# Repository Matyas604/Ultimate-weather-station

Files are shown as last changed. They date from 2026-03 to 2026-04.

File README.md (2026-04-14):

# Ultimate weather station
For a long time, I’ve wanted to know the current temperature, humidity, air quality, and more outside. Since weather forecasts are never accurate for my exact location, I wanted to know what the conditions really are. So, since I already have a lot of experience, I decided to build a complete weather station that would measure the values I wanted, based exactly on the sensors I chose. And since I have a [Home Assistant](https://www.home-assistant.io/) at home, I could make the station smart and monitor the data from anywhere.

This project was more about 3D modeling than PCB design, but in the end, I’m very satisfied.

## Features
- **Contains sensors:** [SHT45](https://sensirion.com/media/documents/33FD6951/67EB9032/HT_DS_Datasheet_SHT4x_5.pdf), [BMP280](https://www.bosch-sensortec.com/media/boschsensortec/downloads/datasheets/bst-bmp280-ds001.pdf), [SGP41](https://sensirion.com/media/documents/5FE8673C/61E96F50/Sensirion_Gas_Sensors_Datasheet_SGP41.pdf), and the [AS3935](https://cdn.sparkfun.com/assets/learn_tutorials/9/2/1/AS3935_Datasheet_EN_v2.pdf) and [LM393](https://www.onsemi.com/download/data-sheet/pdf/lm393-d.pdf) integrated circuits  
- **It can measure:** [temperature](https://en.wikipedia.org/wiki/Temperature), [humidity](https://en.wikipedia.org/wiki/Humidity), [pressure](https://en.wikipedia.org/wiki/Atmospheric_pressure), [air quality](https://en.wikipedia.org/wiki/Air_quality_index), [lightning distance and energy](https://en.wikipedia.org/wiki/Lightning), [wind speed](https://en.wikipedia.org/wiki/Wind_speed) and whether it is raining
- It's connected to [Home Assistant](https://www.home-assistant.io/), so I can use the data to set up automations and monitor the readings even when I'm not at home
- The [ESP32-S3](https://documentation.espressif.com/esp32-s3_datasheet_en.pdf) is the brain of the entire station
- It has two PCBs, one main board and another with sensors located inside the [radiation shield](https://en.wikipedia.org/wiki/Stevenson_screen) that measure the readings. They are connected to each other with a 7-wire cable
- It has pull-up resistors for I2C on the main board, additional resistors can be added on the sensor board to extend the cable length beyond 2 meters
- It is programmable via USB-C
- It is powered by a 5V two-wire cable

⚠️The screw and nuts for the anemometer and the rods for the radiation shield must be made of brass, because brass is non-magnetic and therefore will not interfere with the lightning detection antenna, unlike iron or steel!

## CAD model
It includes a box for the main board and a radiation shield, which is secured with M5 rods and nuts, on top is an anemometer propeller for measuring wind speed. I’ll be placing the weather station on the balcony, so I’ve made a mount for it. It will be attached to the railing, which has a 14° slope, so the mount is designed to keep the radiation shield straight. The shield is connected to the mount with an M6 rod and M6 nuts, there is also a mount for the rain sensor. The railing mount is secured with two parts connected by M6 bolts and nuts. **All parts must be printed using at least ABS, but ASA would be much better, they must also be white!** They will be kept outdoors permanently, and ASA is a material that is highly resistant to UV radiation, sunlight, and rain. It is also very strong, so it can withstand strong winds.

<p align="center">
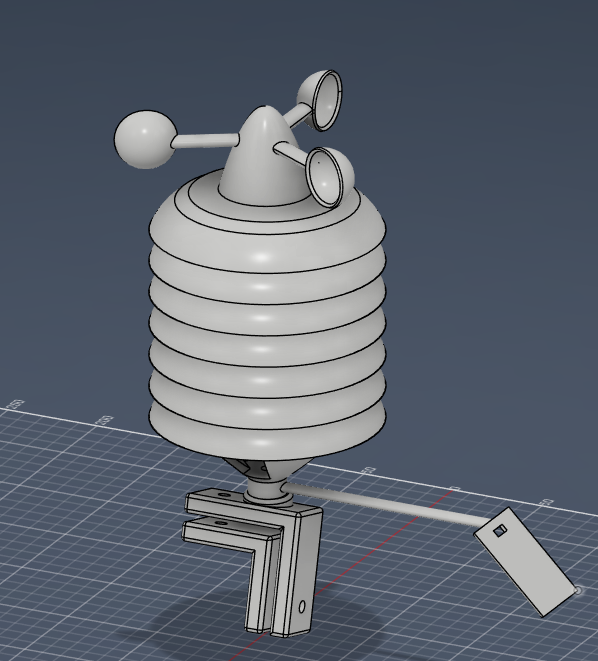
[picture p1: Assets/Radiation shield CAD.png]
Radiation shield CAD
  
</p>
<p align="center">
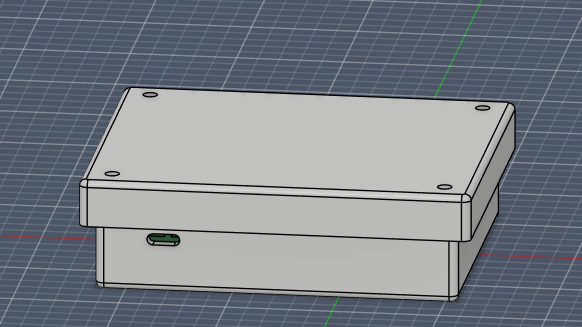
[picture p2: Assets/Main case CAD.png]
Main case CAD
  
</p>
<p align="center">
  <strong>Made in Fusion360</strong>
</p>

## PCBs
### Main PCB:
<p align="center">
  Schematic
</p>
<p align="center">
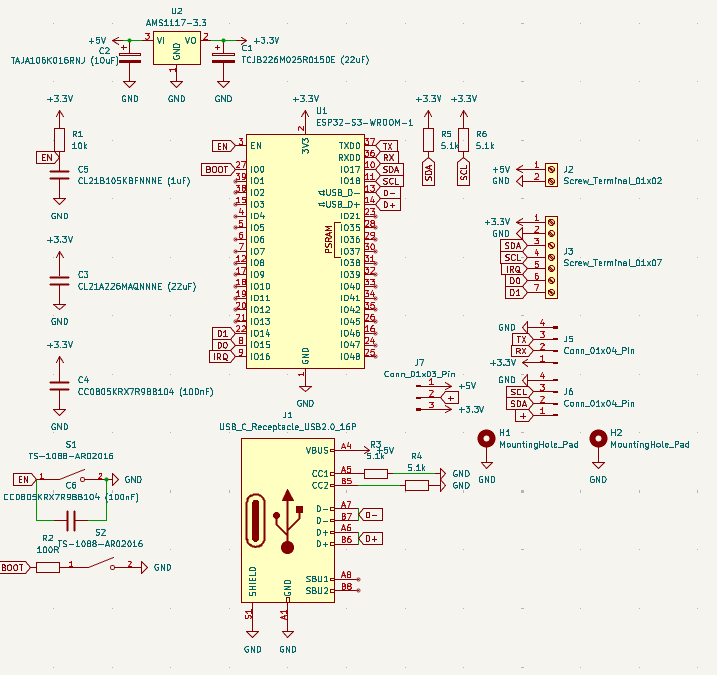
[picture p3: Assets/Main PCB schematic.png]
Main PCB schematic
  
</p>
<p align="center">
  PCB
</p>
<p align="center">
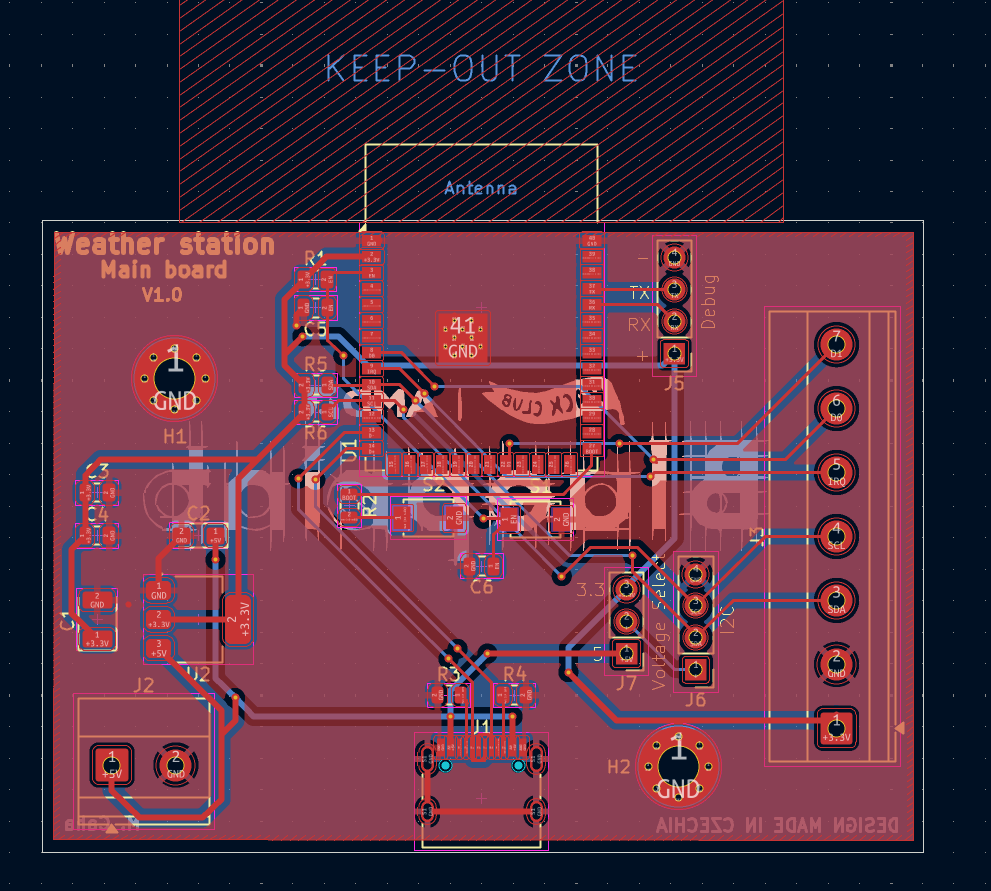
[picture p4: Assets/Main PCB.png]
Main PCB
  
</p>

### Sensors PCB:
<p align="center">
  Schematic
</p>
<p align="center">
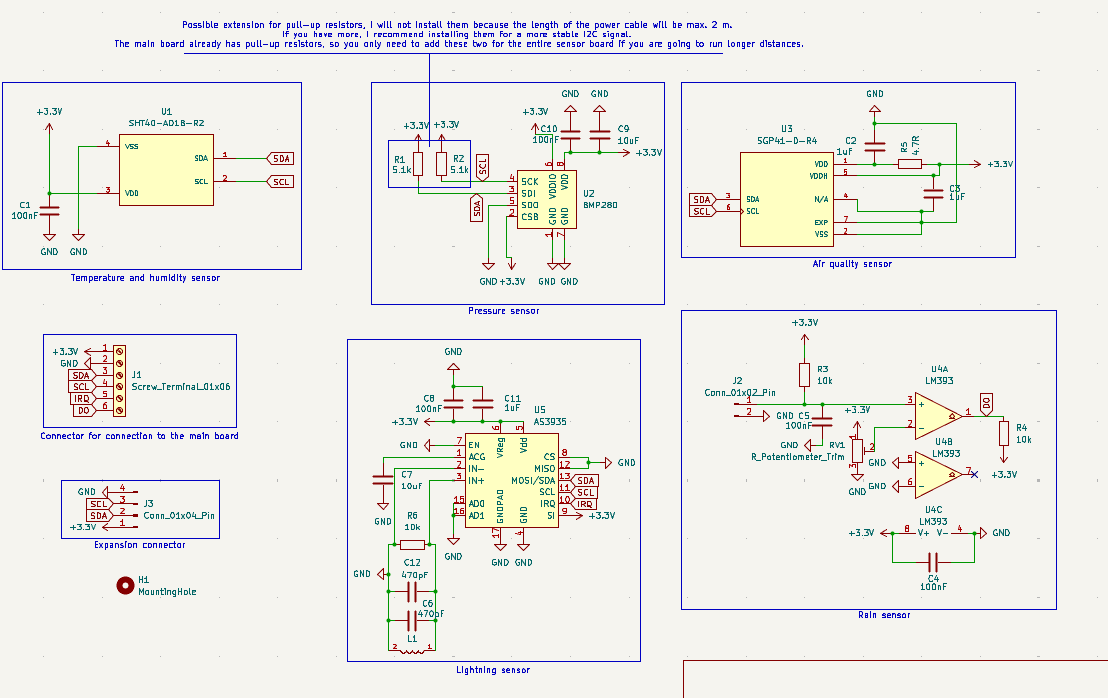
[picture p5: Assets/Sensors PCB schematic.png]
Sensors PCB schematic
  
</p>
<p align="center">
  PCB
</p>
<p align="center">
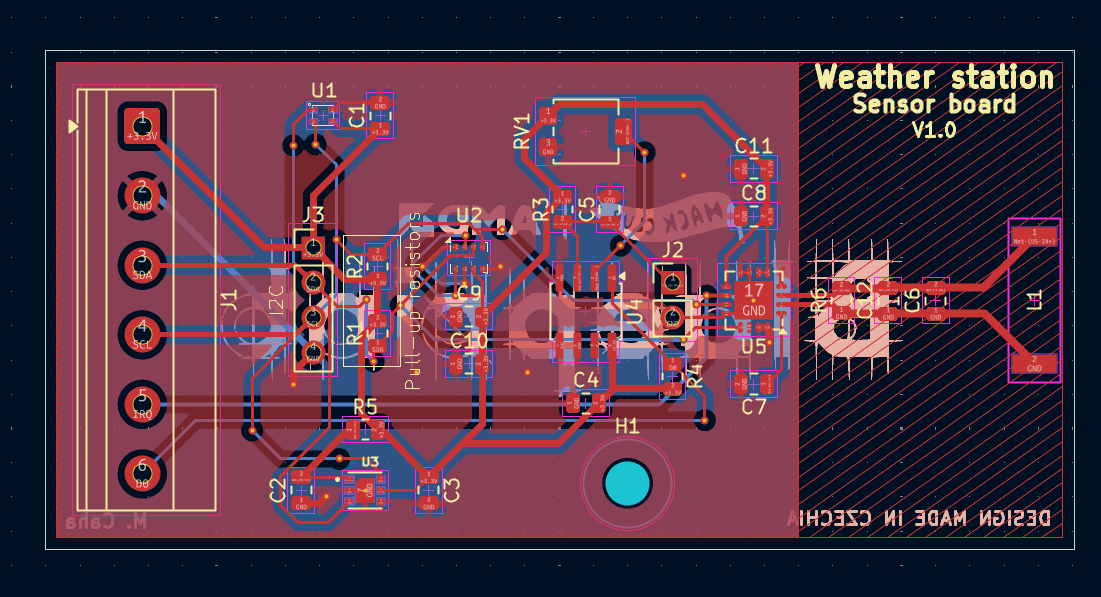
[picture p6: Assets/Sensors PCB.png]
Sensors PCB
  
</p>
<p align="center">
  <strong>Made in KiCad</strong>
</p>

## Wiring diagram
<p align="center">
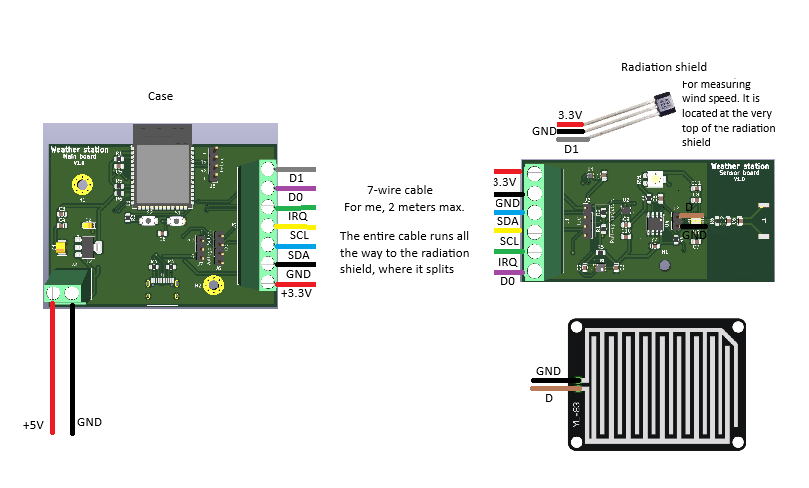
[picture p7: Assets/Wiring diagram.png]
Wiring diagram
  
</p>

## Firmware
This weather station uses [ESPHome](https://esphome.io/) firmware. It is programmed via the USB-C port on the main board. Thanks to ESPHome, it connects to [Home Assistant](https://www.home-assistant.io/), where I can then create various automations and view data from anywhere.

## BOM
It's very long, so you can find it in .csv format [here](https://github.com/Matyas604/Ultimate-weather-station/blob/main/BOM.csv).  
Please read additional information about the BOM [here](https://github.com/Matyas604/Ultimate-weather-station/blob/main/BOM%20info.md).

## Notes for v2 upgrades
Since I anticipated potential upgrades, I added additional I2C ports to both the main board and the sensor board. On the main board, you can also select a voltage of 5V or 3.3V, so you can connect a lot of other things. I did this so I wouldn’t have to replace the entire board when adding expansions. The main board also features a very powerful ESP32, which has enough performance for further expansion. I plan to add the following over time:
- A rain gauge that measures the amount of rainfall
- A dust sensor for measuring **PM1.0**, **PM2.5**, **PM4**, and **PM10** particles, which can then be used in combination with the **SGP41** to calculate air [**Quality Index (AQI)**](https://en.wikipedia.org/wiki/Air_quality_index) values
- Wind direction
- UV and light sensor

## License
This project is licensed under the GNU GPL v3.
```
Matyas604/Ultimate-weather-station - Custom weather station for Home Assistant running on an ESP32
Copyright (C) 2026 Matyáš Caha

This program is free software: you can redistribute it and/or modify
it under the terms of the GNU General Public License as published by
the Free Software Foundation, either version 3 of the License, or
(at your option) any later version.

This program is distributed in the hope that it will be useful,
but WITHOUT ANY WARRANTY; without even the implied warranty of
MERCHANTABILITY or FITNESS FOR A PARTICULAR PURPOSE. See the
GNU General Public License for more details.

You should have received a copy of the GNU General Public License
along with this program. If not, see <https://www.gnu.org/licenses/>.
```

<hr>

<p align="center">
  Made with ❤️ by <a href="https://github.com/Matyas604">@Matyas604</a>
</p>

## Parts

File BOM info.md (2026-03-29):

|Total|Price (USD)|Description|
|-|:-:|:-:|
|**BOM Total**|184.54|Total amount|
|**BOM Total without screws and nuts**|168.77|Total amount without steel screws and nuts|

## Some information about the BOM:

The **AS3935** and **MA5532-AE** components aren’t available on LCSC, but only on other websites where shipping costs $30. So I’ll buy the module from AliExpress, desolder these two components from it, and then use them on my PCB. This will be the best approach, because 95% of the module’s price is for the components, and shipping is free. The **MA5532-AE** component will desolder very easily, and since the **AS3935** has no pins, it will also desolder very easily and without damage.  
**Websites where these components are available:**  
[AS3935](https://cz.mouser.com/ProductDetail/ScioSense/AS3935-BQFT?qs=YVUHYZFLFLudUiUyjH%252FhsQ%253D%253D)  
[MA5532-AE](https://www.coilcraft.com/en-us/products/rf/rfid-transponders/x-y-axis-transponder-coil-2mhz/ma5532/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)

Above, I listed the total amount and the amount excluding steel screws and nuts. If the total amount is too high, I can buy the screws at a local hardware store, where I can purchase exactly the number of pieces I need for cheap. On AliExpress, there aren’t any listings that contain just a few screws or nuts; they come in packs of dozens, which is why they’re so expensive. I need some specific screws and nuts (the brass ones) which I can’t just buy at a regular store, and they’re there specifically so they don’t interfere with the lightning sensor.  

I originally wanted to have the PCB manufactured through JLCPCBA because they would have all the components on hand, but the **SHT45**, **SGP41**, and **BMP280** sensors are very sensitive to high-temperature soldering. JLCPCBA charges an extra $30 for low-temperature soldering, not including the assembly cost, so I’ll save a lot even if I have to pay more for shipping. I have low-temperature solder paste and a hot plate, so I won’t damage the sensors. I already have plenty of experience with SMD soldering.

## Cart photos:
### JLCPCB:
<p align="center">
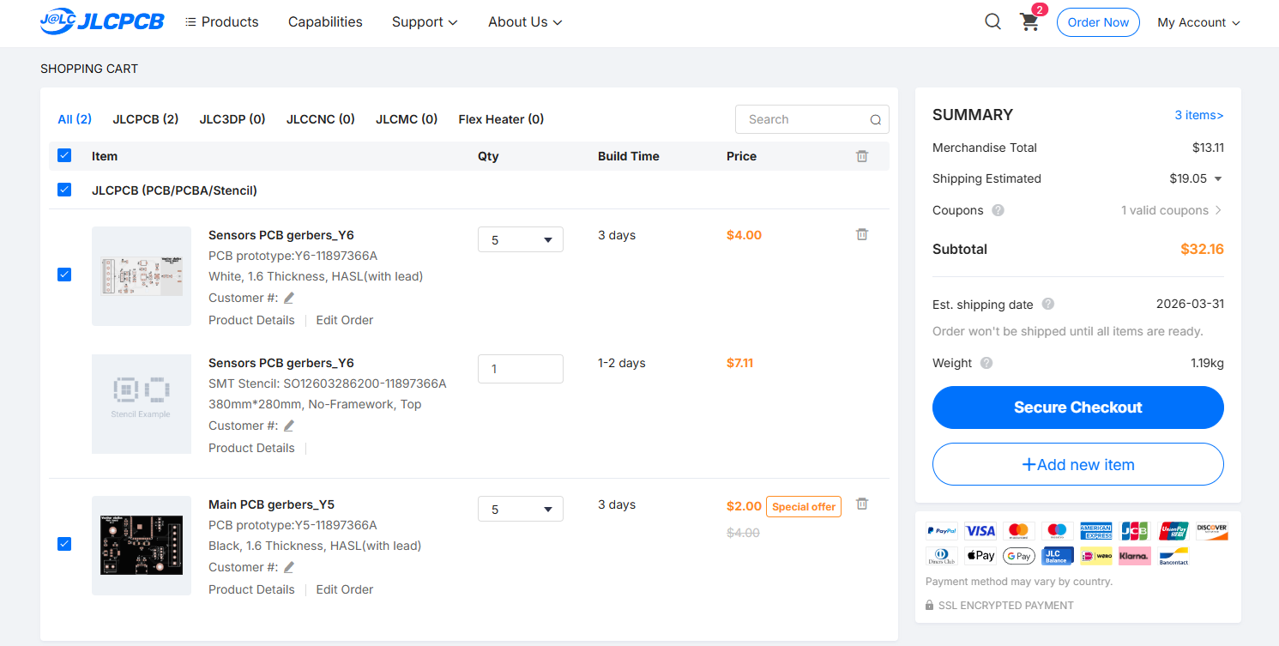
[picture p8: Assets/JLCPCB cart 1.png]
JLCPCB cart 1
  
</p>
<p align="center">
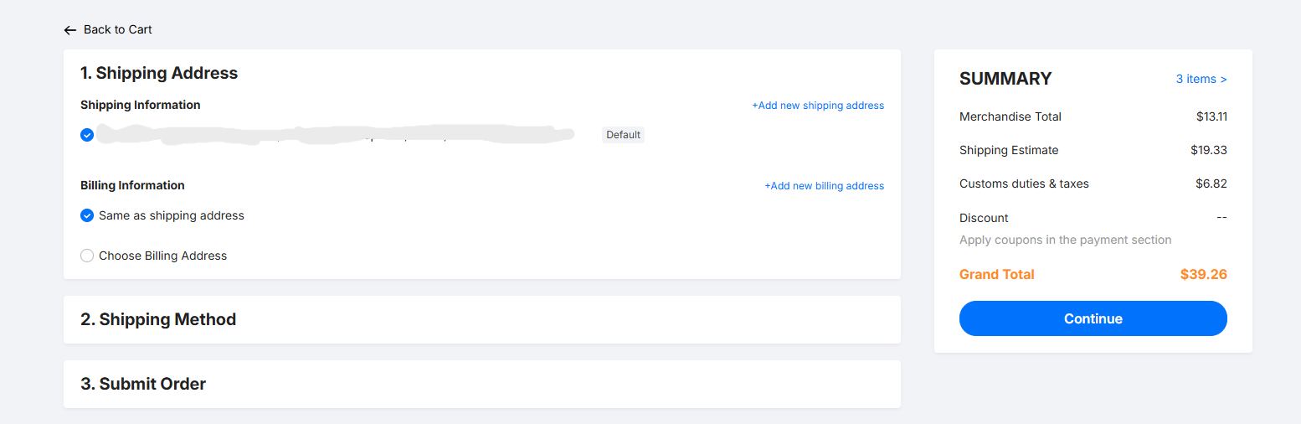
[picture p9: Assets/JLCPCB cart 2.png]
JLCPCB cart 2
  
</p>

### LCSC:
<p align="center">
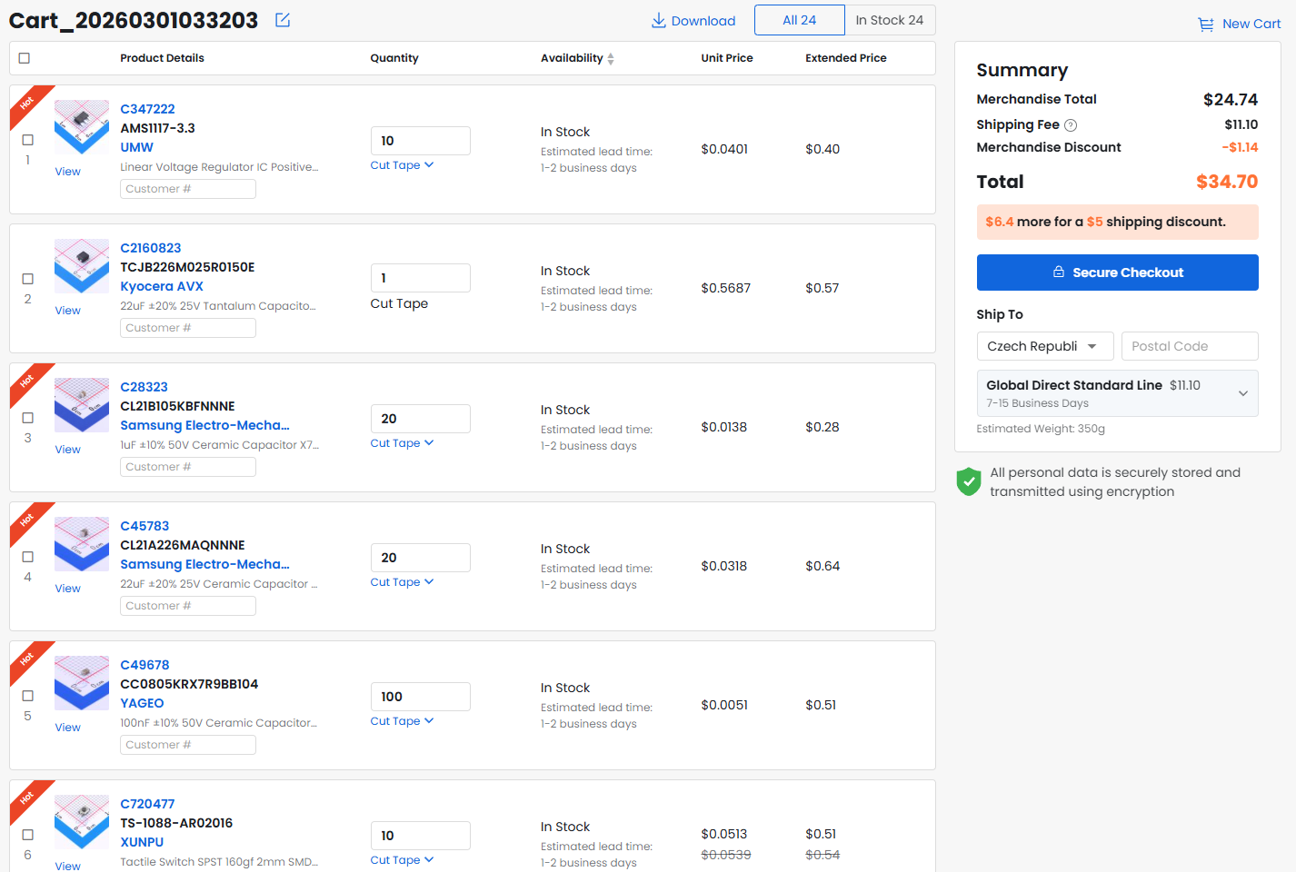
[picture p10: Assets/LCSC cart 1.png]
LCSC cart 1
  
</p>
<p align="center">
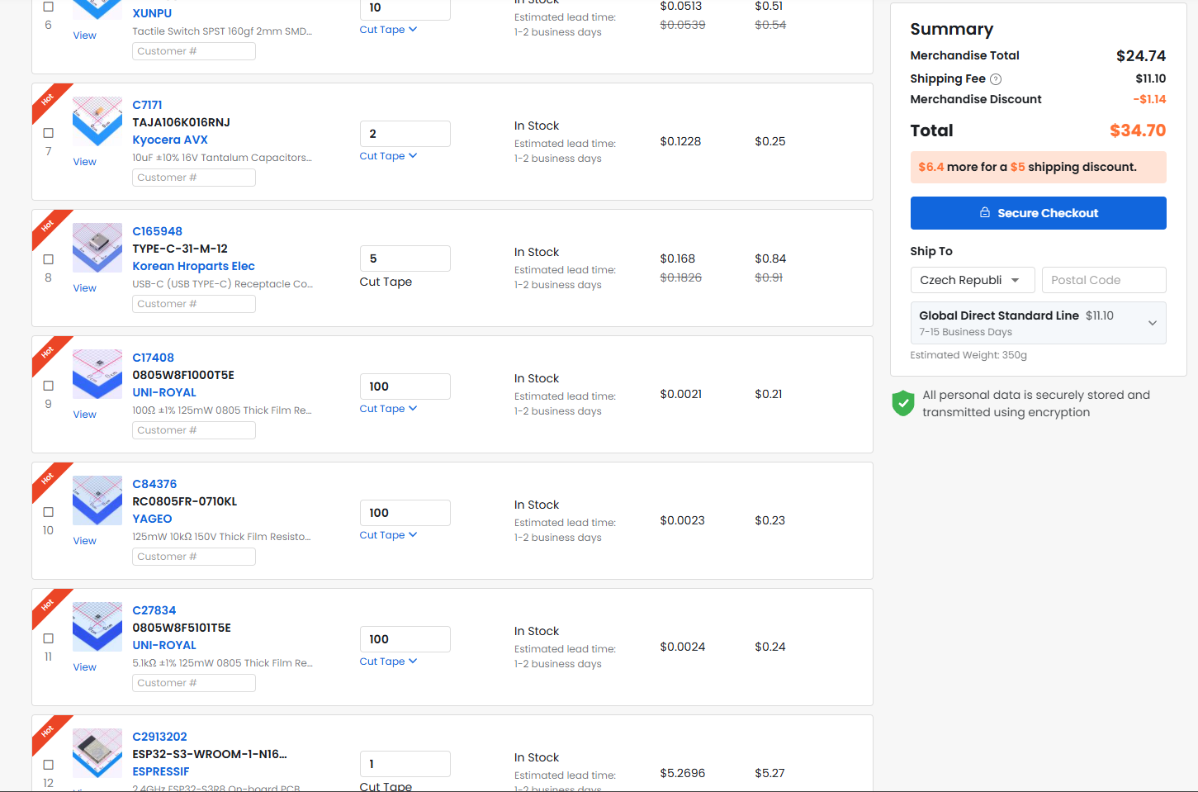
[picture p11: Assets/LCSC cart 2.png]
LCSC cart 2
  
</p>
<p align="center">
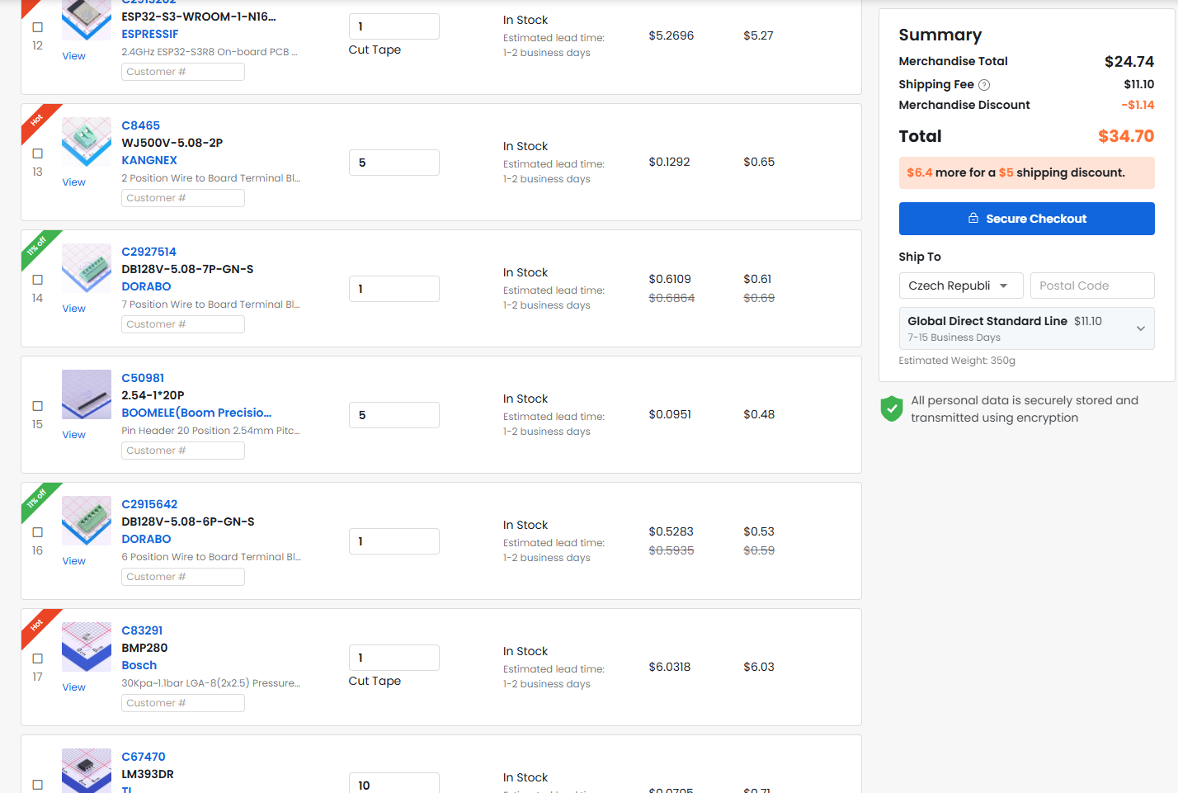
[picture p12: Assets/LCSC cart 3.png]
LCSC cart 3
  
</p>
<p align="center">
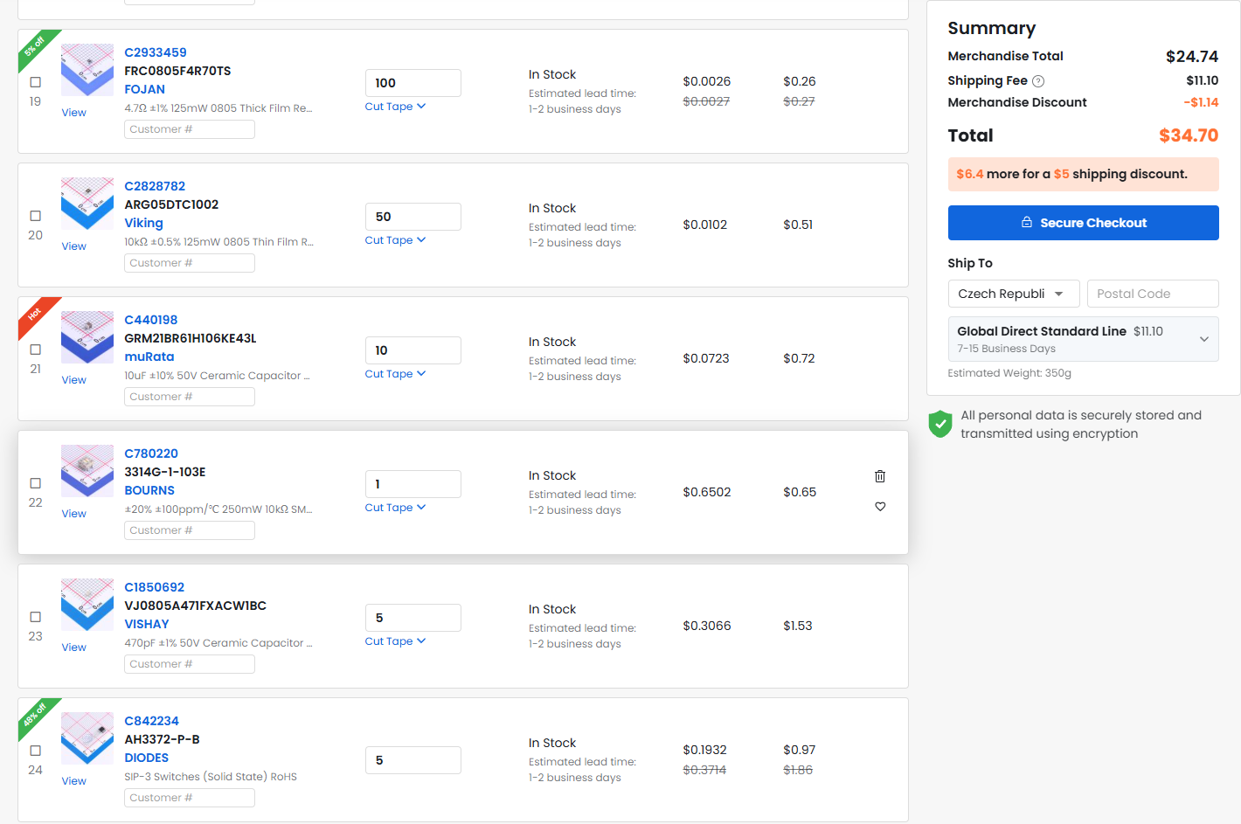
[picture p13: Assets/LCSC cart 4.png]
LCSC cart 4
  
</p>

### Aliexpress:
<p align="center">
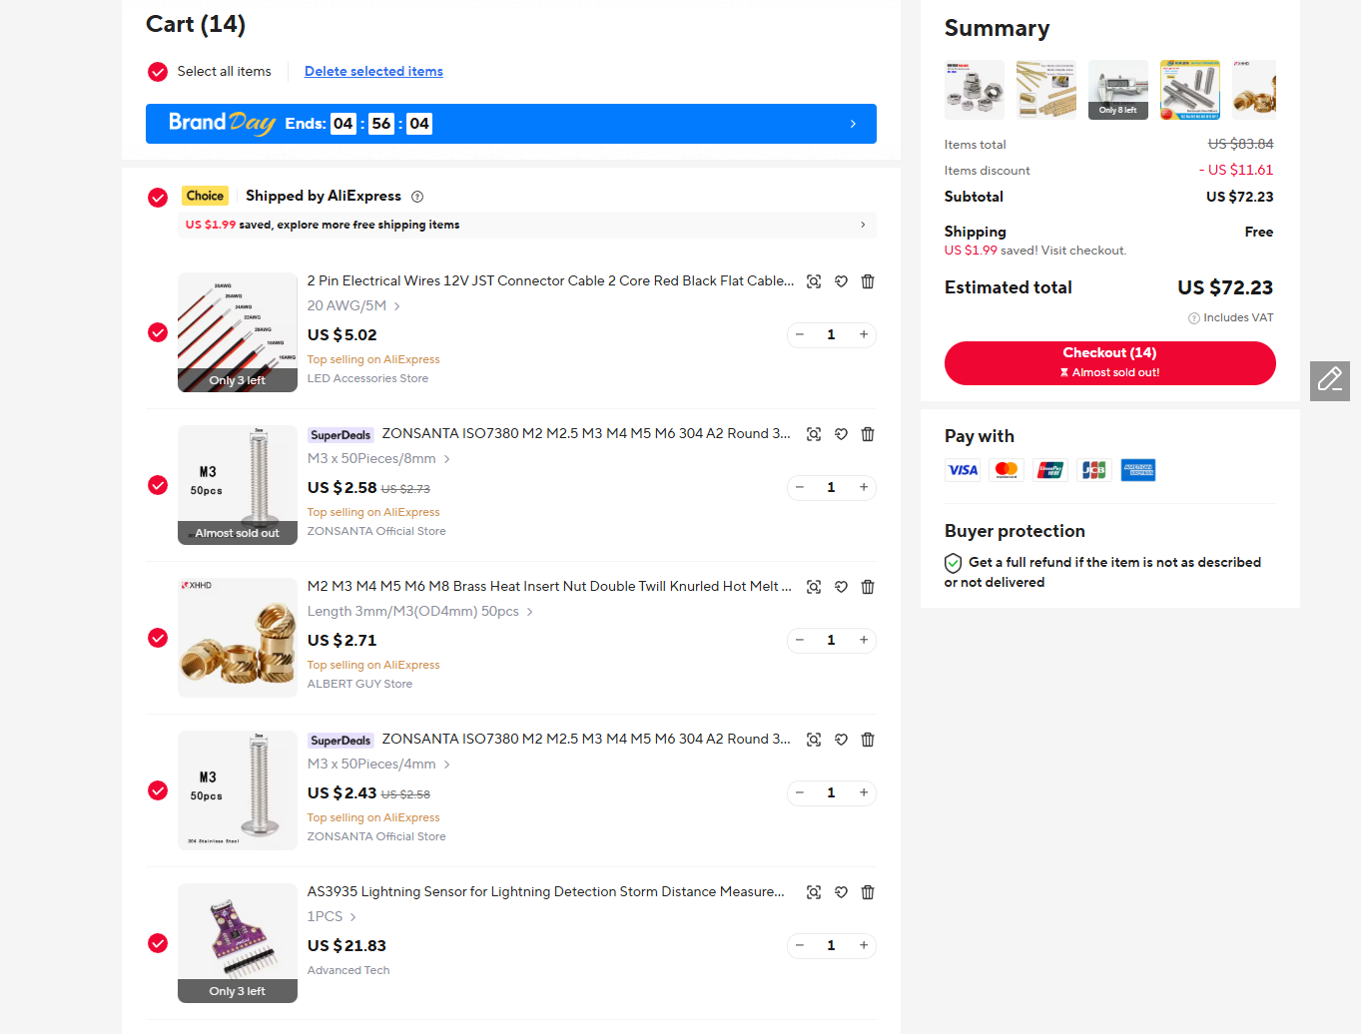
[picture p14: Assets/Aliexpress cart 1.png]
Aliexpress cart 1
  
</p>
<p align="center">
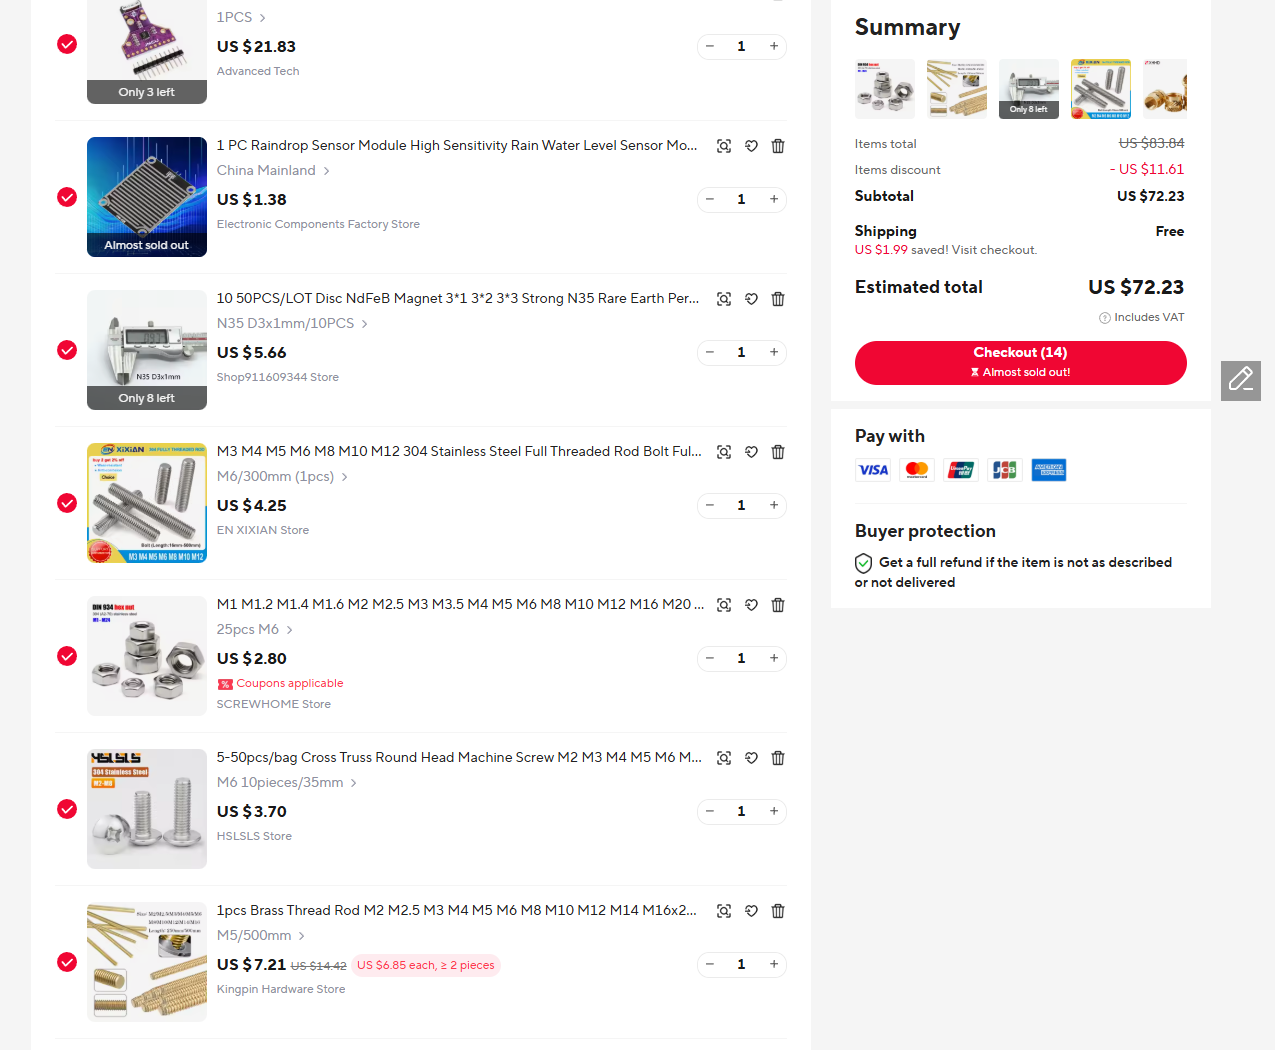
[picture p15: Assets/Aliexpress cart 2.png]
Aliexpress cart 2
  
</p>
<p align="center">
  Aliexpress cart 3
</p>

### Tme.eu:
<p align="center">
  Tme.eu cart
</p>

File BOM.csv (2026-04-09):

Item | Qty. | Min. Qty. | Price (USD) | Link
AMS1117-3.3 | 1 | 10 | 0.4 | https://www.lcsc.com/product-detail/C347222.html?s_z=n_AMS1117
TCJB226M025R0150E | 1 | 1 | 0.57 | https://www.lcsc.com/product-detail/C2160823.html?s_z=n_TCJB226M025R0150E
CL21B105KBFNNNE | 4 | 20 | 0.26 | https://www.lcsc.com/product-detail/C28323.html?s_z=n_CL21B105KBFNNNE
CL21A226MAQNNNE | 1 | 20 | 0.64 | https://www.lcsc.com/product-detail/C45783.html?s_z=n_CL21A226MAQNNNE
CC0805KRX7R9BB104 | 7 | 100 | 0.51 | https://www.lcsc.com/product-detail/C49678.html?s_z=n_CC0805KRX7R9BB104
TS-1088-AR02016 | 2 | 10 | 0.51 | https://www.lcsc.com/product-detail/C720477.html?s_z=n_TS-1088-AR02016
TAJA106K016RNJ | 1 | 2 | 0.25 | https://www.lcsc.com/product-detail/C7171.html?s_z=n_TAJA106K016RNJ%2520
TYPE-C-31-M-12 | 1 | 5 | 0.84 | https://www.lcsc.com/product-detail/C165948.html?s_z=n_C165948
RC0805FR-0710KL | 3 | 100 | 0.23 | https://www.lcsc.com/product-detail/C84376.html
0805W8F1000T5E | 1 | 100 | 0.21 | https://www.lcsc.com/product-detail/C17408.html
0805W8F5101T5E | 6 | 100 | 0.24 | https://www.lcsc.com/product-detail/C27834.html
ESP32-S3-WROOM-1-N16R8 | 1 | 1 | 5.27 | https://www.lcsc.com/product-detail/C2913202.html?s_z=n_C2913202
2.54-1*20P | 1 | 5 | 0.48 | https://www.lcsc.com/product-detail/C50981.html
WJ500V-5.08-2P | 1 | 5 | 0.65 | https://www.lcsc.com/product-detail/C8465.html
DB128V-5.08-7P-GN-S | 1 | 1 | 0.61 | https://www.lcsc.com/product-detail/C2927514.html
DB128V-5.08-6P-GN-S | 1 | 1 | 0.53 | https://www.lcsc.com/product-detail/C2915642.html
BMP280 | 1 | 1 | 6.03. | https://www.lcsc.com/product-detail/C83291.html?s_z=n_BMP280
LM393DR | 1 | 10 | 0.71 | https://www.lcsc.com/product-detail/C67470.html?s_z=n_C67470
FRC0805F4R70TS | 1 | 100 | 0.26 | https://www.lcsc.com/product-detail/C2933459.html
ARG05DTC1002 | 1 | 50 | 0.51 | https://www.lcsc.com/product-detail/C2828782.html
GRM21BR61H106KE43L | 2 | 10 | 0.72 | https://www.lcsc.com/product-detail/C440198.html
3314G-1-103E | 1 | 1 | 0.65 | https://www.lcsc.com/product-detail/C780220.html?s_z=n_3314G-1-103E
VJ0805A471FXACW1BC | 2 | 5 | 1.53 | https://www.lcsc.com/product-detail/C1850692.html
AH3372-P-B | 1 | 5 | 0.97 | https://www.lcsc.com/product-detail/C2900627.html?s_z=n_SS451A
LCSC shipping | 1 | 1 | 11.1 | https://www.lcsc.com/
SHT45 | 1 | 1 | 5.76 | https://www.tme.eu/cz/details/sht45-ad1f-r2/cidla-vlhkosti/sensirion/3-000-886/
SGP41 | 1 | 1 | 6.66 | https://www.tme.eu/cz/details/sgp41-d-r4/snimace-plynu/sensirion/3-000-060/
TME shipping + VAT | 1 | 1 | 9.32 | https://www.tme.eu/cz/
AS3935 and MA5532-AE | 1 | 1 | 21.83 | https://www.aliexpress.com/item/32828658129.html
5*10*4mm Bearing | 2 | 10 | 4.06 | https://www.aliexpress.com/item/1005006520267674.html
M5*20mm brass screw | 1 | 10 | 4.1 | https://www.aliexpress.com/item/1005009875439058.html
M5 nut | 8 | 30 | 4.5 | https://www.aliexpress.com/item/1005010400168277.html
M5 thread rod 500mm | 1 | 1 | 7.21 | https://www.aliexpress.com/item/1005010032176735.html
M6 screw 35mm | 2 | 10 | 3.7 | https://www.aliexpress.com/item/1005010704591089.html
M6 nut | 2 | 25 | 2.8 | https://www.aliexpress.com/item/32977174437.html
M6 thread rod 300mm | 1 | 1 | 4.25 | https://www.aliexpress.com/item/1005008551456774.html
3*1mm magnet N35 | 1 | 10 | 5.66 | https://www.aliexpress.com/item/1005010687292929.html
Rain sensor | 1 | 1 | 1.38 | https://www.aliexpress.com/item/1005009470544835.html
M3 4mm screw | 3 | 50 | 2.43 | https://www.aliexpress.com/item/4000981220901.html
M3 8mm screw | 4 | 50 | 2.43 | https://www.aliexpress.com/item/4000981220901.html
M3 heat insert | 7 | 50 | 2.71 | https://www.aliexpress.com/item/1005008666672949.html
Main PCB | 1 | 1 | 2 | https://jlcpcb.com/
Sensors PCB | 1 | 1 | 4 | https://jlcpcb.com/
Sensors PCB stencil | 1 | 1 | 3.05 | https://jlcpcb.com/
JLCPCB shipping + taxes | 1 | 1 | 16.4 | https://jlcpcb.com/
2 Core Cable 5m | 1 | 1 | 5 | Local hardware store
7 Core Cable 2m | 1 | 1 | 5 | Local hardware store
3D printed parts | 15 |  | 12 | Printing legion
PCB varnish | 1 | 1 | 7.5 | https://www.tme.eu/cz/details/pvb16-100ml/ochranne-a-stinici-povlaky/ag-termopasty/art-agt-232/

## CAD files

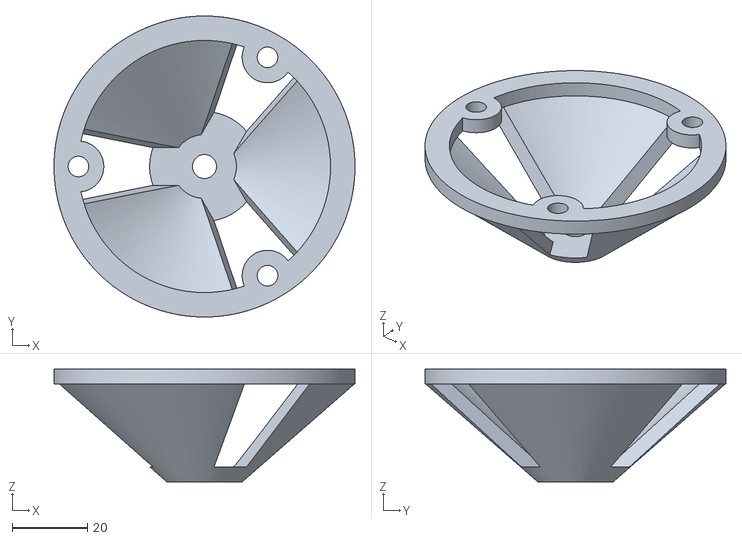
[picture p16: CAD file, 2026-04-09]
Production/3D parts/Radiation shield bracket.stl
80.0 x 80.0 x 30.0

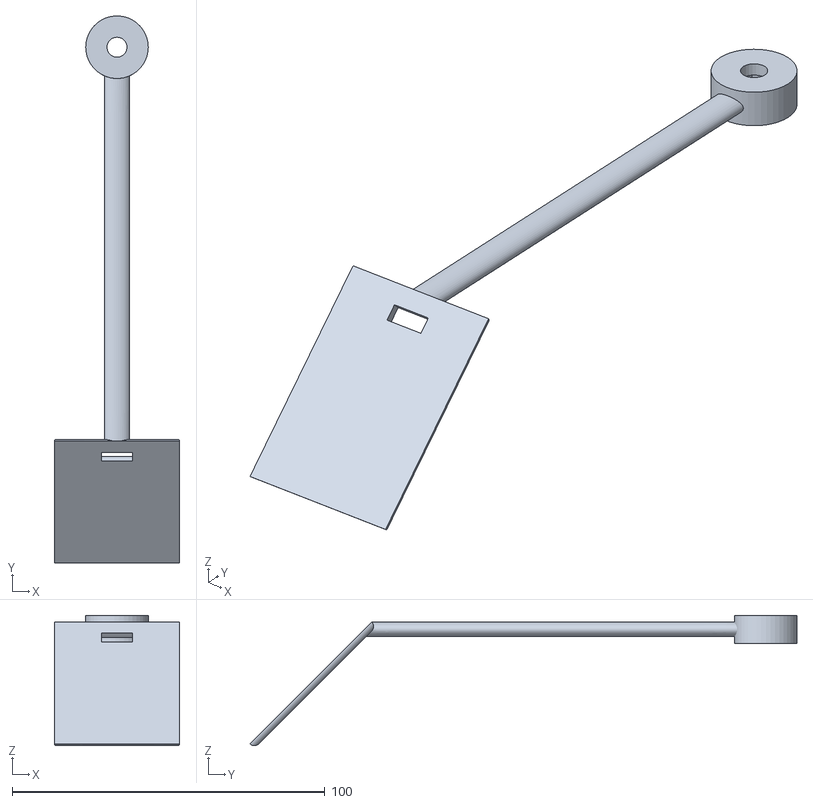
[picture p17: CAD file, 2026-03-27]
Production/3D parts/Rain sensor holder.stl
40.0 x 174.8 x 41.7

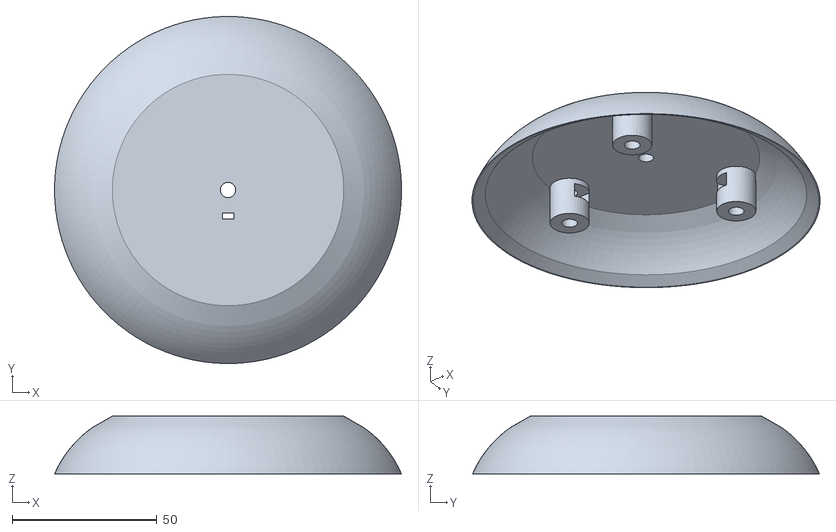
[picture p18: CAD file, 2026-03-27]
Production/3D parts/Radiation shield top.stl
120.0 x 120.0 x 20.0

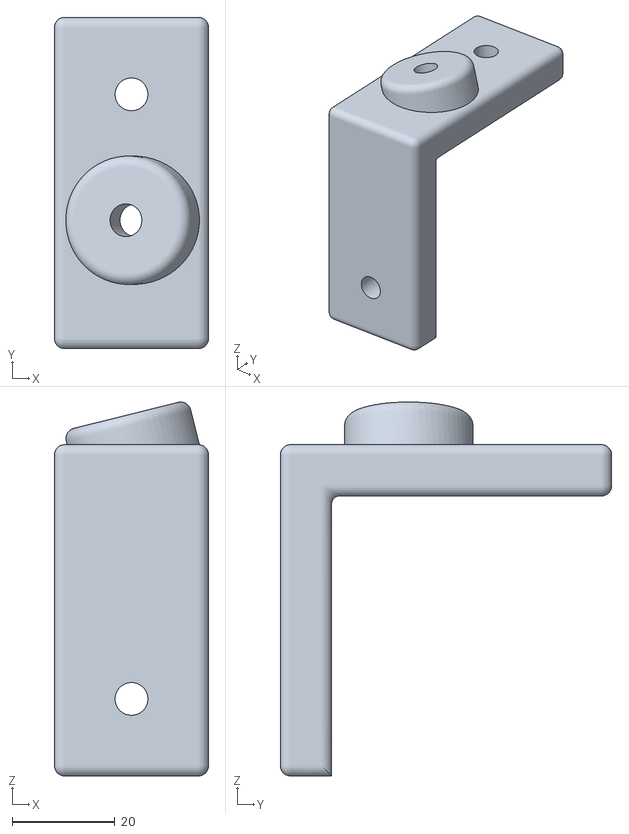
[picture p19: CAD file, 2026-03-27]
Production/3D parts/Railing mount top.stl
30.0 x 64.5 x 72.8

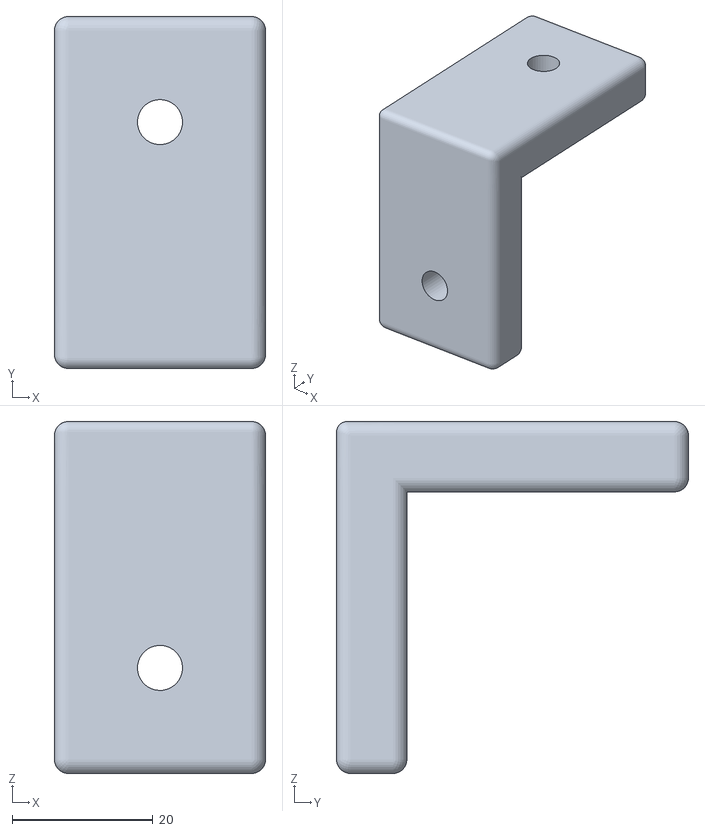
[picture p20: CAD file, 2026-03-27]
Production/3D parts/Railing mount bottom.stl
30.0 x 50.0 x 50.0

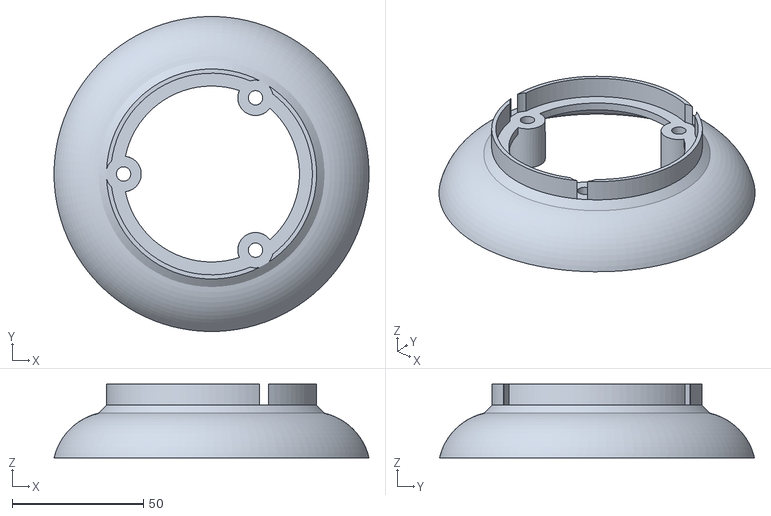
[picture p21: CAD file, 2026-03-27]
Production/3D parts/Radiation shield second part.stl
120.0 x 120.0 x 28.0

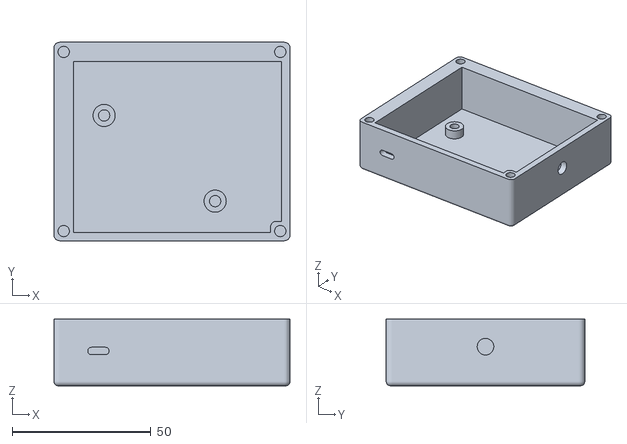
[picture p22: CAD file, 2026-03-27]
Production/3D parts/Case bottom.stl
85.0 x 71.5 x 24.0

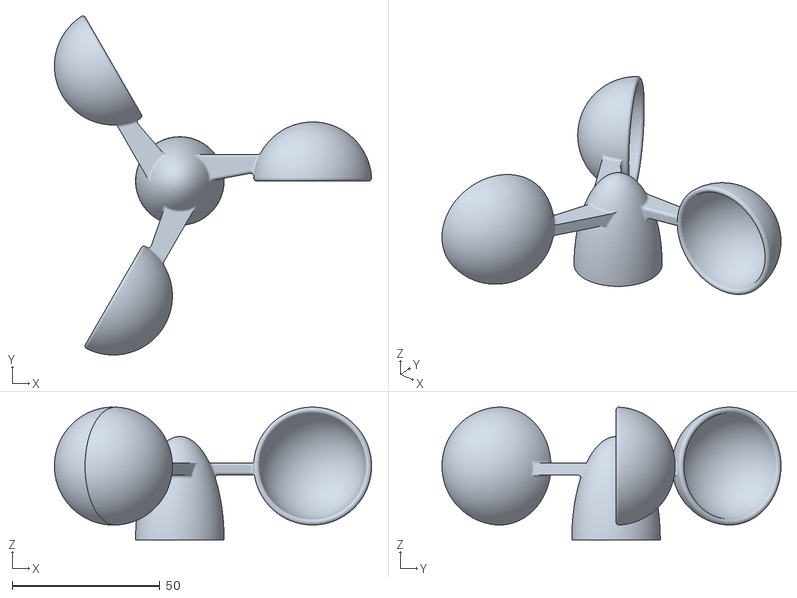
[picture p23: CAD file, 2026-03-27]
Production/3D parts/Anaemometer.stl
107.5 x 114.9 x 45.0

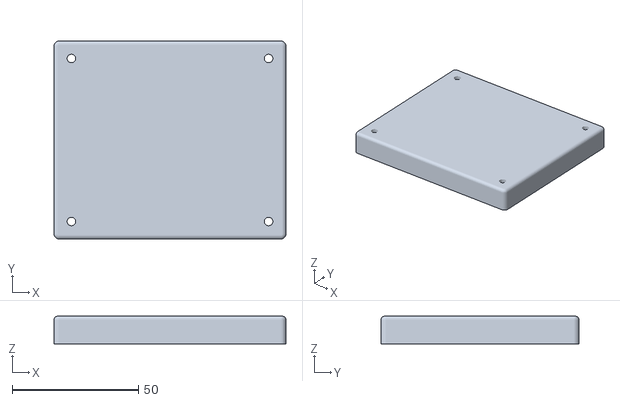
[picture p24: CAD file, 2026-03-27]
Production/3D parts/Case top.stl
91.8 x 78.3 x 11.0

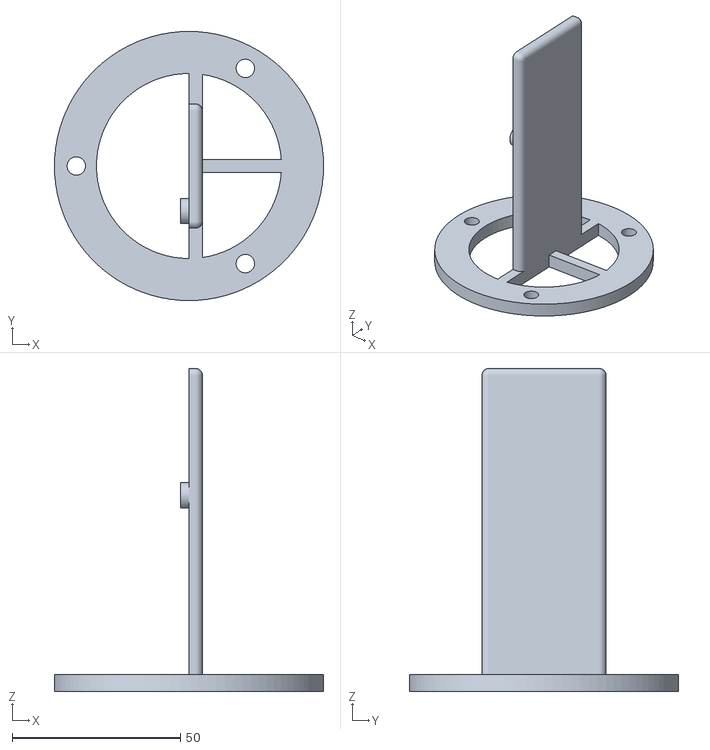
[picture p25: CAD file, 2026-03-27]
Production/3D parts/Radiation shield PCB holder.stl
80.0 x 80.0 x 96.0

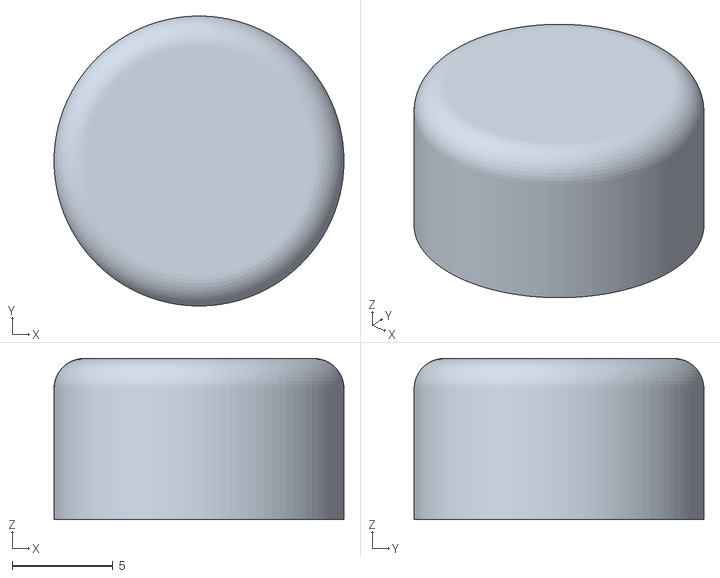
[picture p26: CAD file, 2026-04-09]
Production/3D parts/M6 nut cap.stl
14.4 x 14.4 x 8.00

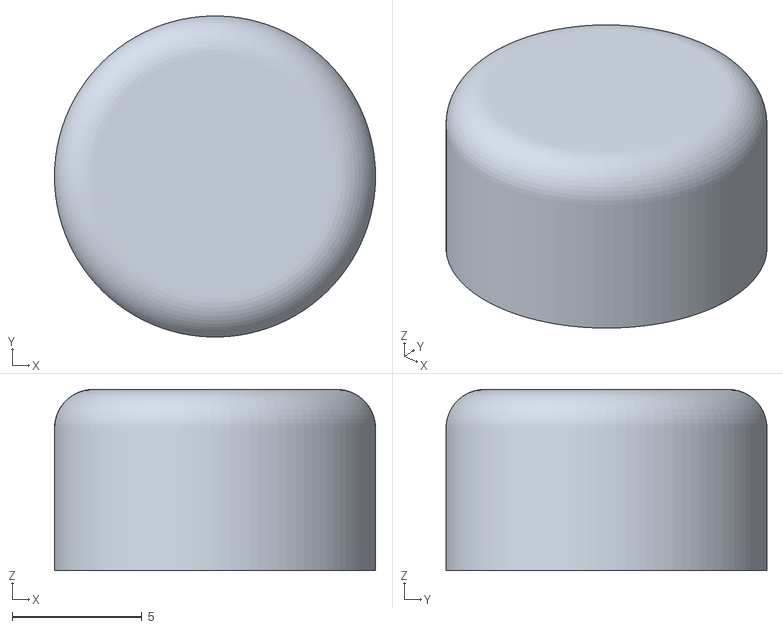
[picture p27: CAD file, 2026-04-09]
Production/3D parts/M5 nut cap.stl
12.4 x 12.4 x 7.00

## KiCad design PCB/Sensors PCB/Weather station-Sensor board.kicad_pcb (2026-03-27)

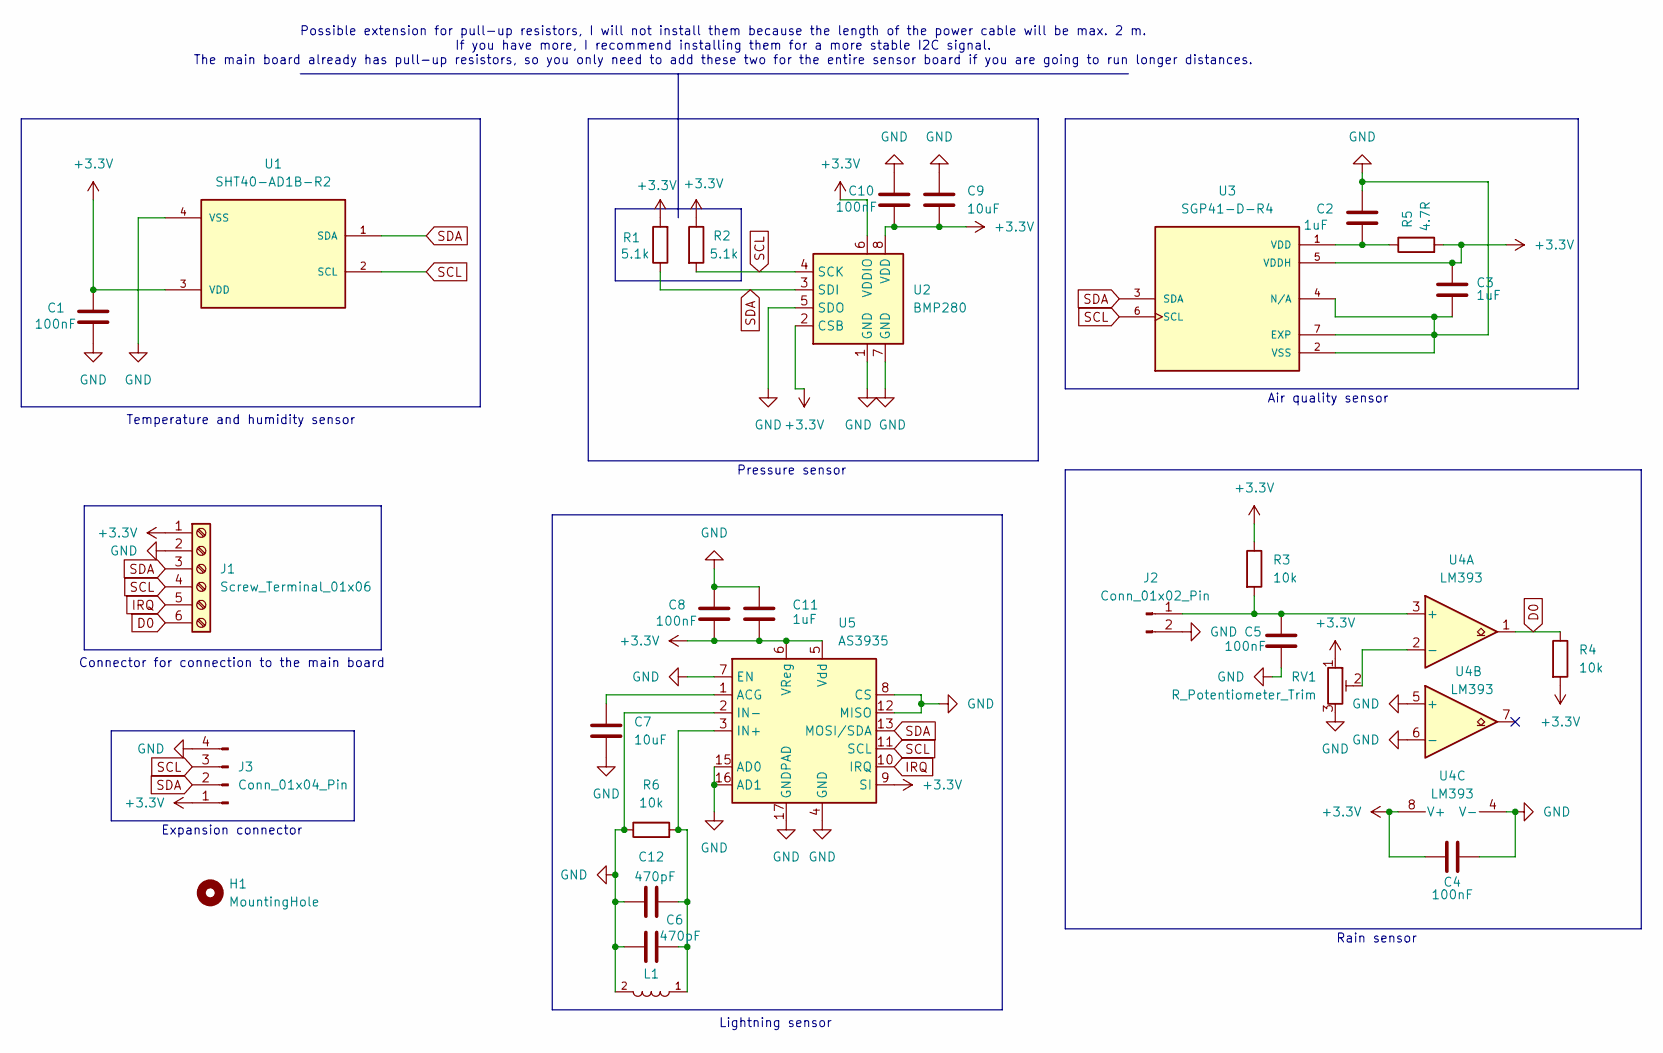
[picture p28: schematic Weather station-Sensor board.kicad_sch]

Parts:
C1, C4, C5, C8, C10: 100nF; C_0805_2012Metric
C2, C3, C11: 1uF; C_0805_2012Metric
C6, C12: 470pF; C_0805_2012Metric
C7, C9: 10uF; C_0805_2012Metric
H1: MountingHole; MountingHole_3.2mm_M3
J1: Screw_Terminal_01x06; TerminalBlock_Phoenix_MKDS-1,5-6-5.08_1x06_P5.08mm_Horizont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
J2: Conn_01x02_Pin; PinHeader_1x02_P2.54mm_Vertical
J3: Conn_01x04_Pin; PinHeader_1x04_P2.54mm_Vertical
L1: 100uH; MA5532-AE
R1, R2: 5.1k; R_0805_2012Metric
R3, R4, R6: 10k; R_0805_2012Metric
R5: 4.7R; R_0805_2012Metric
RV1: R_Potentiometer_Trim; Potentiometer_Bourns_3314G_Vertical
U1: SHT40-AD1B-R2; SHT4X
U2: BMP280; Bosch_LGA-8_2x2.5mm_P0.65mm_ClockwisePinNumbering
U3: SGP41-D-R4; XDCR_SGP41-D-R4; PARTREV 1.0
U4: LM393; SOIC-8_3.9x4.9mm_P1.27mm
U5: AS3935; MLPQ-16-1EP_4x4mm_P0.65mm_EP2.8x2.8mm

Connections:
+3.3V: C1.1, C3.1, C4.2, C8.2, C9.2, C10.2, C11.2, J1.1, J3.1, R1.2, R2.1, R3.1, R4.2, R5.2, RV1.1, U1.3 (VDD), U2.2 (CSB), U2.6 (VDDIO), U2.8 (VDD), U3.5 (VDDH), U4.8 (V+), U5.5 (Vdd), U5.6 (VReg), U5.9 (SI)
D0: J1.6, R4.1, U4.1
GND: C1.2, C2.1, C3.2, C4.1, C5.2, C6.1, C7.2, C8.1, C9.1, C10.1, C11.1, C12.1, J1.2, J2.2, J3.4, L1.2, R6.1, RV1.3, U1.4 (VSS), U2.1 (GND), U2.5 (SDO), U2.7 (GND), U3.2 (VSS), U3.4 (N/A), U3.7 (EXP), U4.4 (V-), U4.5 (+), U4.6 (-), U5.2 (IN-), U5.4 (GND), U5.7 (EN), U5.8 (CS), U5.12 (MISO), U5.15 (AD0), U5.16 (AD1), U5.17 (GNDPAD)
IRQ: J1.5, U5.10 (IRQ)
unnamed: C5.1, J2.1, R3.2, U4.3 (+)
unnamed: C2.2, R5.1, U3.1 (VDD)
unnamed: RV1.2, U4.2 (-)
unnamed: C7.1, U5.1 (ACG)
unnamed: C6.2, C12.2, L1.1, R6.2, U5.3 (IN+)
SCL: J1.4, J3.3, R2.2, U1.2 (SCL), U2.4 (SCK), U3.6 (SCL), U5.11 (SCL)
SDA: J1.3, J3.2, R1.1, U1.1 (SDA), U2.3 (SDI), U3.3 (SDA), U5.13 (MOSI/SDA)

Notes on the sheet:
Lightning sensor
Rain sensor
Expansion connector
Pressure sensor
Connector for connection to the main board
Possible extension for pull-up resistors, I will not install them because the length of the power cable will be max. 2 m. If you have more, I recommend installing them for a more stable I2C signal. The main board already has pull-up resistors, so you only need to add these two for the entire sensor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
Temperature and humidity sensor
Air quality sensor

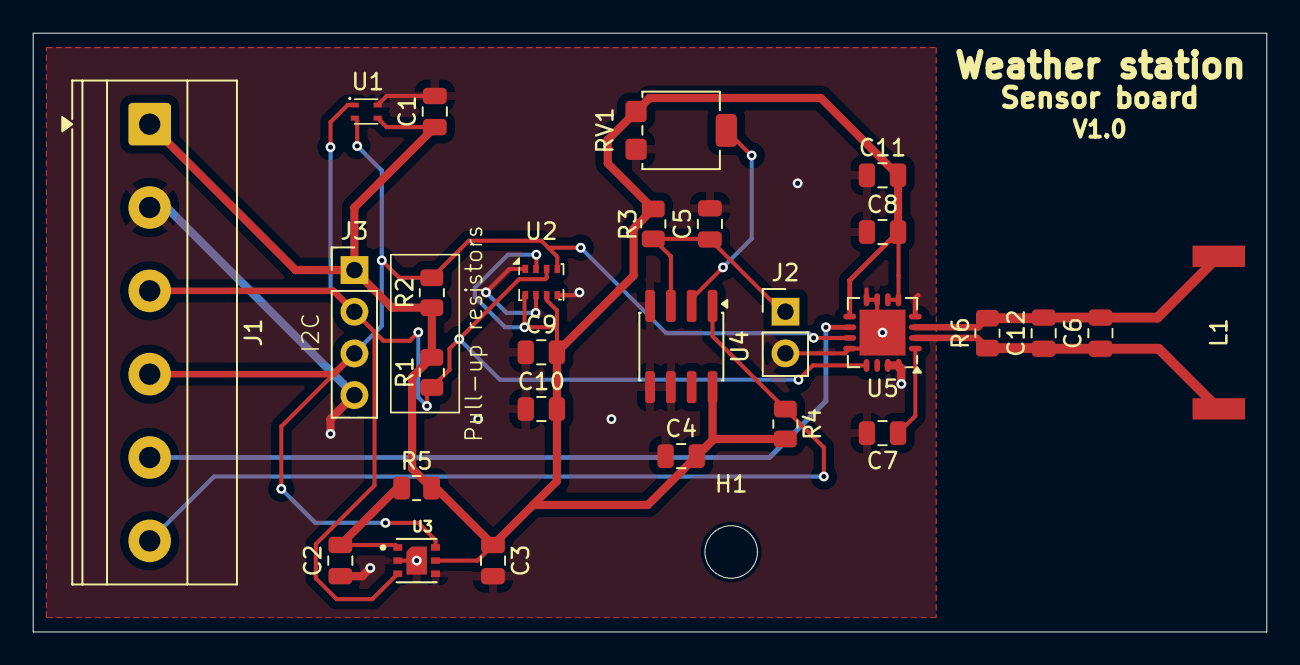
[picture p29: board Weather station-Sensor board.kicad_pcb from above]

Board: 2 copper layers, 75.2 x 36.5 mm, 29 parts (0 on the bottom side), 11 nets.

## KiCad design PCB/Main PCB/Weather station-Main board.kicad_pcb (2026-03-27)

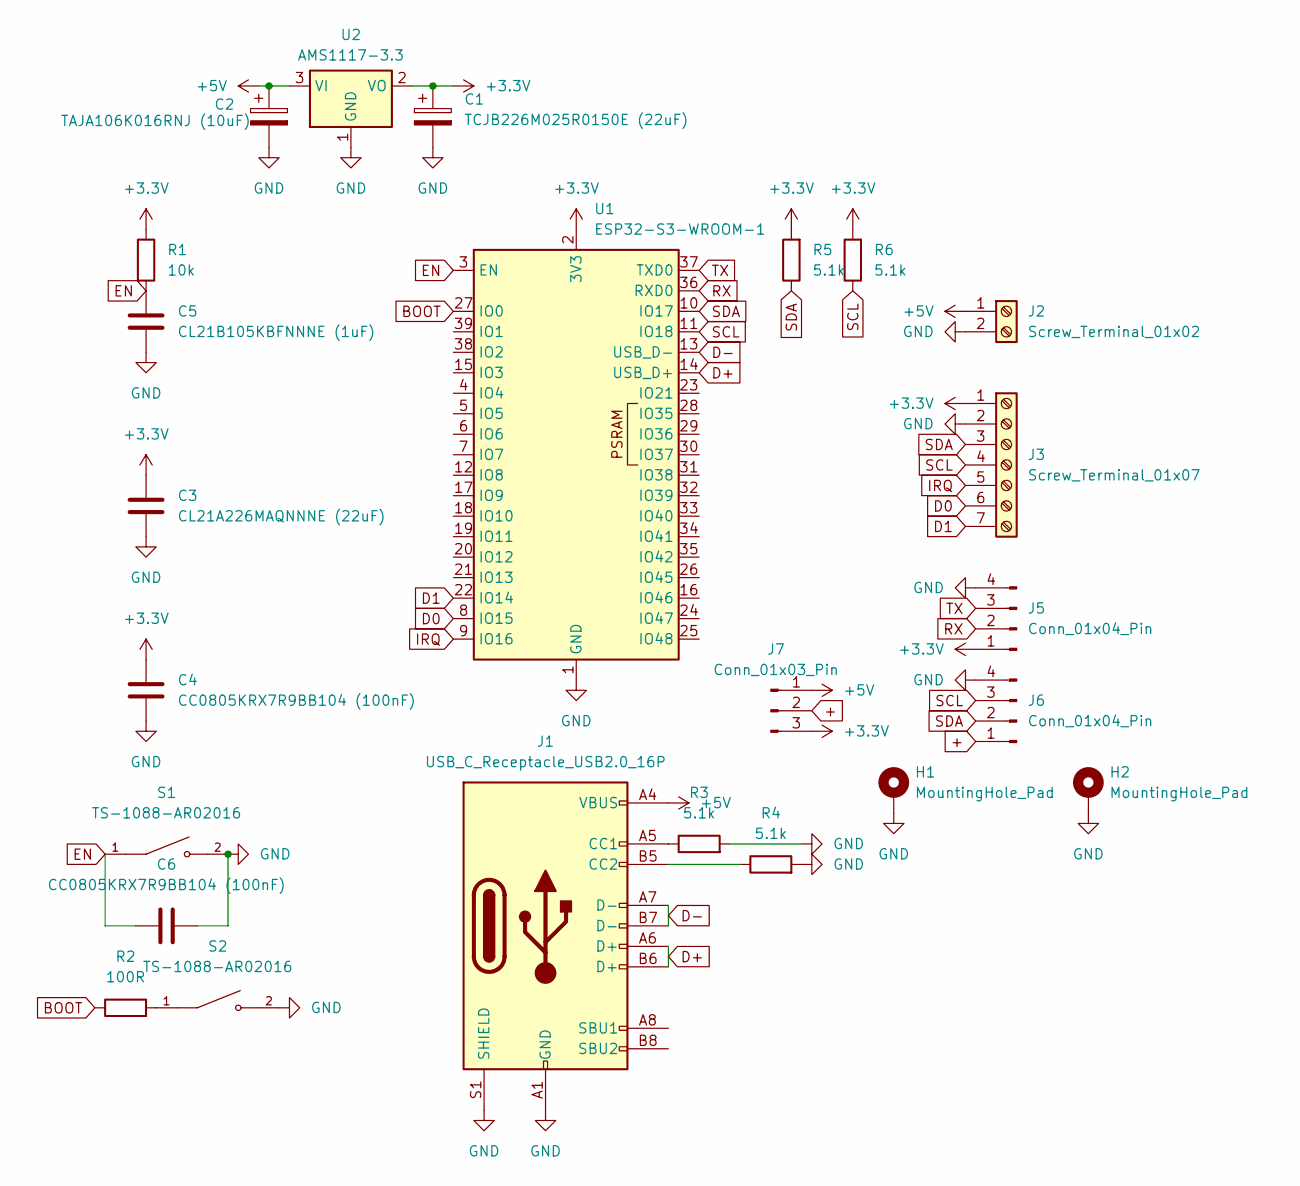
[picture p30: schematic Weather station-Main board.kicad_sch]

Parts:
C1: TCJB226M025R0150E (22uF); CP_EIA-3528-21_Kemet-B
C2: TAJA106K016RNJ (10uF); CP_EIA-3216-18_Kemet-A
C3: CL21A226MAQNNNE (22uF); C_0805_2012Metric
C4, C6: CC0805KRX7R9BB104 (100nF); C_0805_2012Metric
C5: CL21B105KBFNNNE (1uF); C_0805_2012Metric
H1, H2: MountingHole_Pad; MountingHole_3.2mm_M3_Pad_Via
J1: USB_C_Receptacle_USB2.0_16P; USB_C_Receptacle_HRO_TYPE-C-31-M-12
J2: Screw_Terminal_01x02; TerminalBlock_Phoenix_MKDS-1,5-2-5.08_1x02_P5.08mm_Horizont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
J3: Screw_Terminal_01x07; TerminalBlock_Phoenix_MKDS-1,5-7-5.08_1x07_P5.08mm_Horizont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
J5, J6: Conn_01x04_Pin; PinHeader_1x04_P2.54mm_Vertical
J7: Conn_01x03_Pin; PinHeader_1x03_P2.54mm_Vertical
R1: 10k; R_0805_2012Metric
R2: 100R; R_0805_2012Metric
R3, R4, R5, R6: 5.1k; R_0805_2012Metric
S1, S2: TS-1088-AR02016; SW_TS-1088-AR02016; PARTREV N/A
U1: ESP32-S3-WROOM-1
U2: AMS1117-3.3; SOT-223-3_TabPin2

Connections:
+: J6.1, J7.2
+3.3V: C1.1, C3.1, C4.1, J3.1, J5.1, J7.3, R1.1, R5.2, R6.2, U1.2 (3V3), U2.2 (VO)
+5V: C2.1, J1.A4 (VBUS), J1.A9 (VBUS), J1.B4 (VBUS), J1.B9 (VBUS), J2.1, J7.1, U2.3 (VI)
BOOT: R2.1, U1.27 (IO0)
D0: J3.6, U1.8 (IO15)
D1: J3.7, U1.22 (IO14)
D+: J1.A6 (D+), J1.B6 (D+), U1.14 (USB_D+)
D-: J1.A7 (D-), J1.B7 (D-), U1.13 (USB_D-)
EN: C5.2, C6.1, R1.2, S1.1, U1.3 (EN)
GND: C1.2, C2.2, C3.2, C4.2, C5.1, C6.2, H1.1, H2.1, J1.A1 (GND), J1.A12 (GND), J1.B1 (GND), J1.B12 (GND), J1.S1 (SHIELD), J2.2, J3.2, J5.4, J6.4, R3.2, R4.2, S1.2, S2.2, U1.1 (GND), U1.40 (GND), U1.41 (GND), U2.1 (GND)
IRQ: J3.5, U1.9 (IO16)
unnamed: J1.A5 (CC1), R3.1
unnamed: J1.B5 (CC2), R4.1
unnamed: R2.2, S2.1
RX: J5.2, U1.36 (RXD0)
SCL: J3.4, J6.3, R6.1, U1.11 (IO18)
SDA: J3.3, J6.2, R5.1, U1.10 (IO17)
TX: J5.3, U1.37 (TXD0)

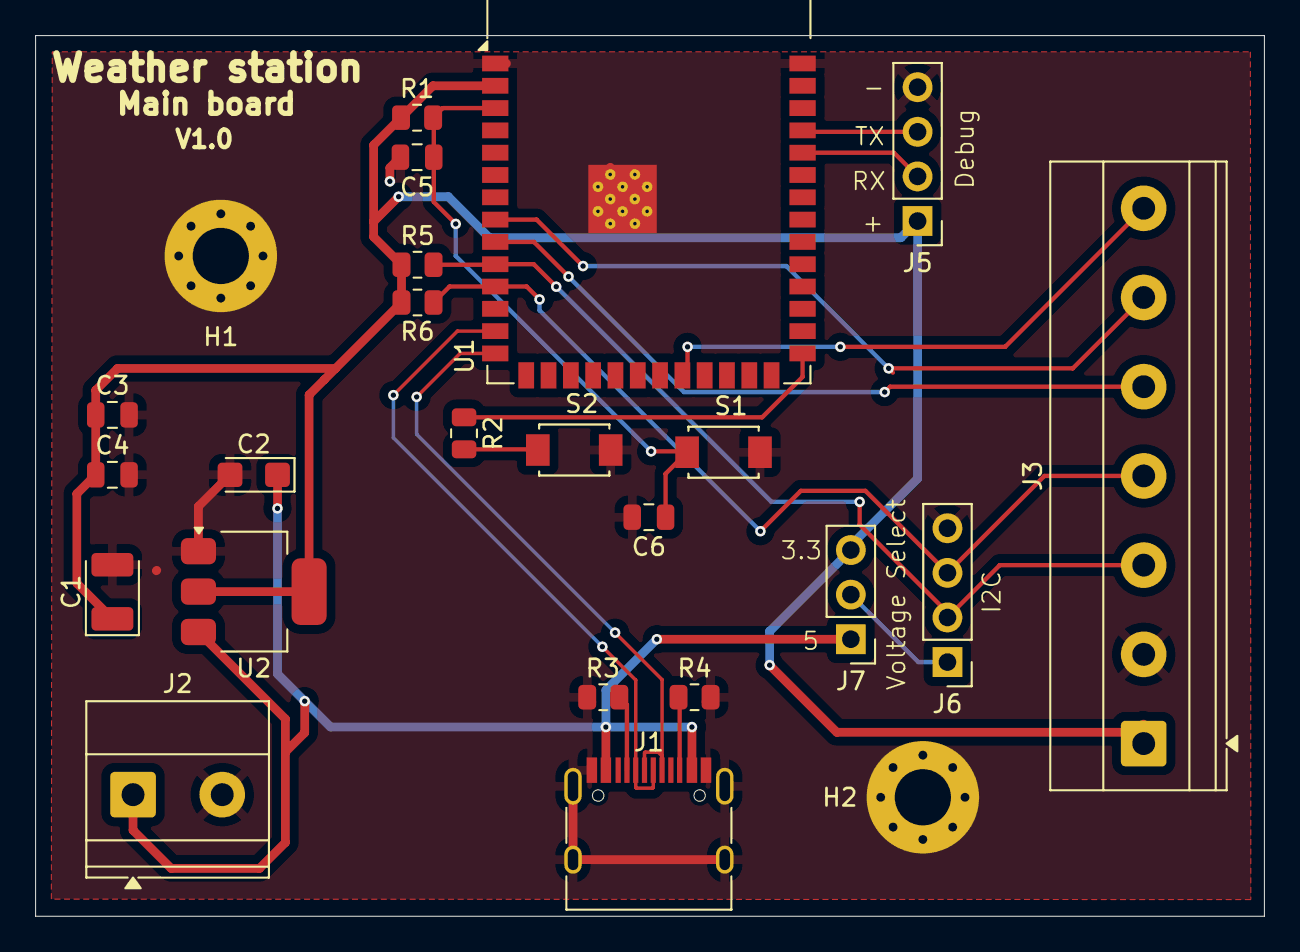
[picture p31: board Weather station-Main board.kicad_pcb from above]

Board: 2 copper layers, 70.0 x 50.1 mm, 24 parts (0 on the bottom side), 18 nets.

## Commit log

2026-03-23 Adding PCB files
    [Weather station-Main board.kicad_pcb, Weather station-Main board.kicad_sch, Weather station-Sensor board.kicad_pcb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]
2026-03-24 Create BOM
    [BOM.csv]
2026-03-24 Main PCB components added
    [BOM.csv]
2026-03-27 Adding files
    [Anaemometer.stl, Case bottom.stl, Case top.stl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]
2026-03-28 Adding sensors PCB parts and assembly parts
    [BOM.csv]
2026-03-28 Create BOM info.md
2026-03-28 Update BOM info.md
2026-03-28 Adding few tings
    [BOM.csv]
2026-03-29 Adding 3D parts
    [BOM.csv]
2026-03-30 Adding Wiring diagram
2026-04-09 Adding nut caps
2026-04-09 Price changes
    [BOM.csv]
